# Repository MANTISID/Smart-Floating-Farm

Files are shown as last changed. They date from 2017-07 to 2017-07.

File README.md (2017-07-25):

# Smart-Floating-Farm
Future Farming Platform in Coastal and Remote Island. Cultivate the future, start from the sea. We submit this project to  Intel Hackathon 2017

## Inspiration
**We want to help people**

We see that local people in Coastal area and Remote Islands having difficulty in planting horticulture because they face the problem of land limitations. We have an idea about making floating platform so people can grow their vegetables at coastal area.
We inspired by [**GROASIS**](https://www.groasis.com/en), [**Seawater Greenhouse**](https://seawatergreenhouse.com/), and [**Hamster Ball-Shaped Solarball**](http://inhabitat.com/hamster-ball-shaped-solarball-uses-the-sun-to-purify-water/). They can grow plants at desert area and have a pure water using desalination process.
Hopefully this platform can help local people to reduce their dependence on supply from mainland, help them make their own food independence and also help to make more money from selling the harvest vegetables. We also can manage these process with supllying seed, provide consultation to user, and preparing the market to sell the vegetables.

## What it does
__**SMART FLOATING FARM (SFF) PLATFORM BUILD TO RECORD, MONITOR, AND MAKE DECISION BASED ON THE RECORD.**__

__**Initialize sensors and output**__

This platform will initialize serial, lcd, RTC (real time clock), sensors, and motor. If RTC cannot be detected, LCD will display error and user must fix it. After RTC is ok, Arduino101 will check communication with ESP8266. Arduino101 send "AT" and wait "OK" from ESP8266.
 
__**Get threshold from Server**__

After receiving "OK", Arduino will command ESP8266 as station mode and get parameter threshold from Server.  These threshold value used to ensure plants are in the range that has been determined by the user. SFF send GET method to server ([This link](http://mantisid.id/api/product/sff_th_r.php?Format=Sys) used to receive sensors threshold). Parameter threshold will be saved as variable.

__**Sensor Measurement**__

This platform record these parameters : soil moisture & temperature, greenhouse temperature & humidity, greenhouse smoke detection, vibration, plant height, time, and light intensity.
 
__**Sending Data to Server**__

Data from sensor compiled as String and send it to Web by ESP8266 using POST method ([Go to this link](http://mantisid.id/api/product/sff_dt_c.php) to send data to WebServer; [Visit this link](http://mantisid.id/api/product/sff_dt_r.php) to see data that received by WebServer from Platform).

__**Output Action**__

Arduino101 check data measurement with threshold received from Server. Based on these threshold, platform will give command automatically to activate LED indicator, water pump, exhaust fan and LED lamps based on sensors reading. After 10 seconds, platform will delay few minutes before the next measurement. While waiting, Arduino101 measure gyro value. 

## How we built it
We use Arduino IDE to built the firmware. We use libraries from internal Arduino IDE and from internet. For external library, we used  [SEEED RGB LCD ](https://github.com/Seeed-Studio/Grove_LCD_RGB_Backlight), [Adafruit DHT11 ](https://github.com/adafruit/DHT-sensor-library), [Adafruit RTC ](https://github.com/adafruit/RTClib), [Adafruit ADS1115 ](https://github.com/adafruit/Adafruit_ADS1X15), [MQ02 Gas Sensor](https://github.com/labay11/MQ-2-sensor-library), [Dallas DS18B20 ](https://github.com/milesburton/Arduino-Temperature-Control-Library), [Rotation from Gyro & Accelerometer](https://forum.arduino.cc/index.php?topic=378779.0), [Time Alarm ](https://github.com/michaelmargolis/arduino_time/tree/master/Time), and [Time Lib ](https://github.com/PaulStoffregen/Time). For internal library, we used Wire, pitches.h, CurieIMU and Software Serial. We used Mario Bros Tune developed by [Dipto Pratyaksa](http://www.linuxcircle.com/2013/03/31/playing-mario-bros-tune-with-arduino-and-piezo-buzzer/) to play sound at the beginning. IMU rotation angle we got from [Erikyo](https://forum.arduino.cc/index.php?topic=378779.0). SFF Arduino sketch can be found at [MANTIS GITHUB](https://github.com/MANTISID/Smart-Floating-Farm).

## Sensor and output configuration
**ARDUINO101   SENSOR/OUTPUT**
- D0    <---->    Tx UART
- D1    <---->    Rx UART
- D2    <---->    GREEN LED INDICATOR
- D3    <---->    RED LED INDICATOR
- D4    <---->    BUZZER
- D5    <---->    DHT11
- D6    <---->    SRF04 ECHO PIN
- D7    <---->    Tx ESP8266
- D8    <---->    Rx ESP8266
- D9    <---->    DS18B20
- D10   <---->    RELAY FOR EXHAUST FAN & SPRAYER
- D11   <---->    RELAY FOR WATER PUMP
- A0    <---->    VIBRATION SENSOR
- A1    <---->    LIGHT SENSOR
- A2    <---->    GREEN LED FOR LIGHTING
- A3    <---->    MQ02 GAS SENSOR

- A4    <---->    SDA
- A5    <---->    SCL

**I2C COMMUNICATION**
- RGB LCD SHIELD
- ADS1115 ADC 16 BIT
    * ADC1    <---->    SOIL MOISTURE SENSOR
    * ADC3    <---->    WATER LEVEL SENSOR
    
**INTERNAL USE:**
- INERTIAL MEASUREMENT UNIT (GYRO & ACCELEROMETER)

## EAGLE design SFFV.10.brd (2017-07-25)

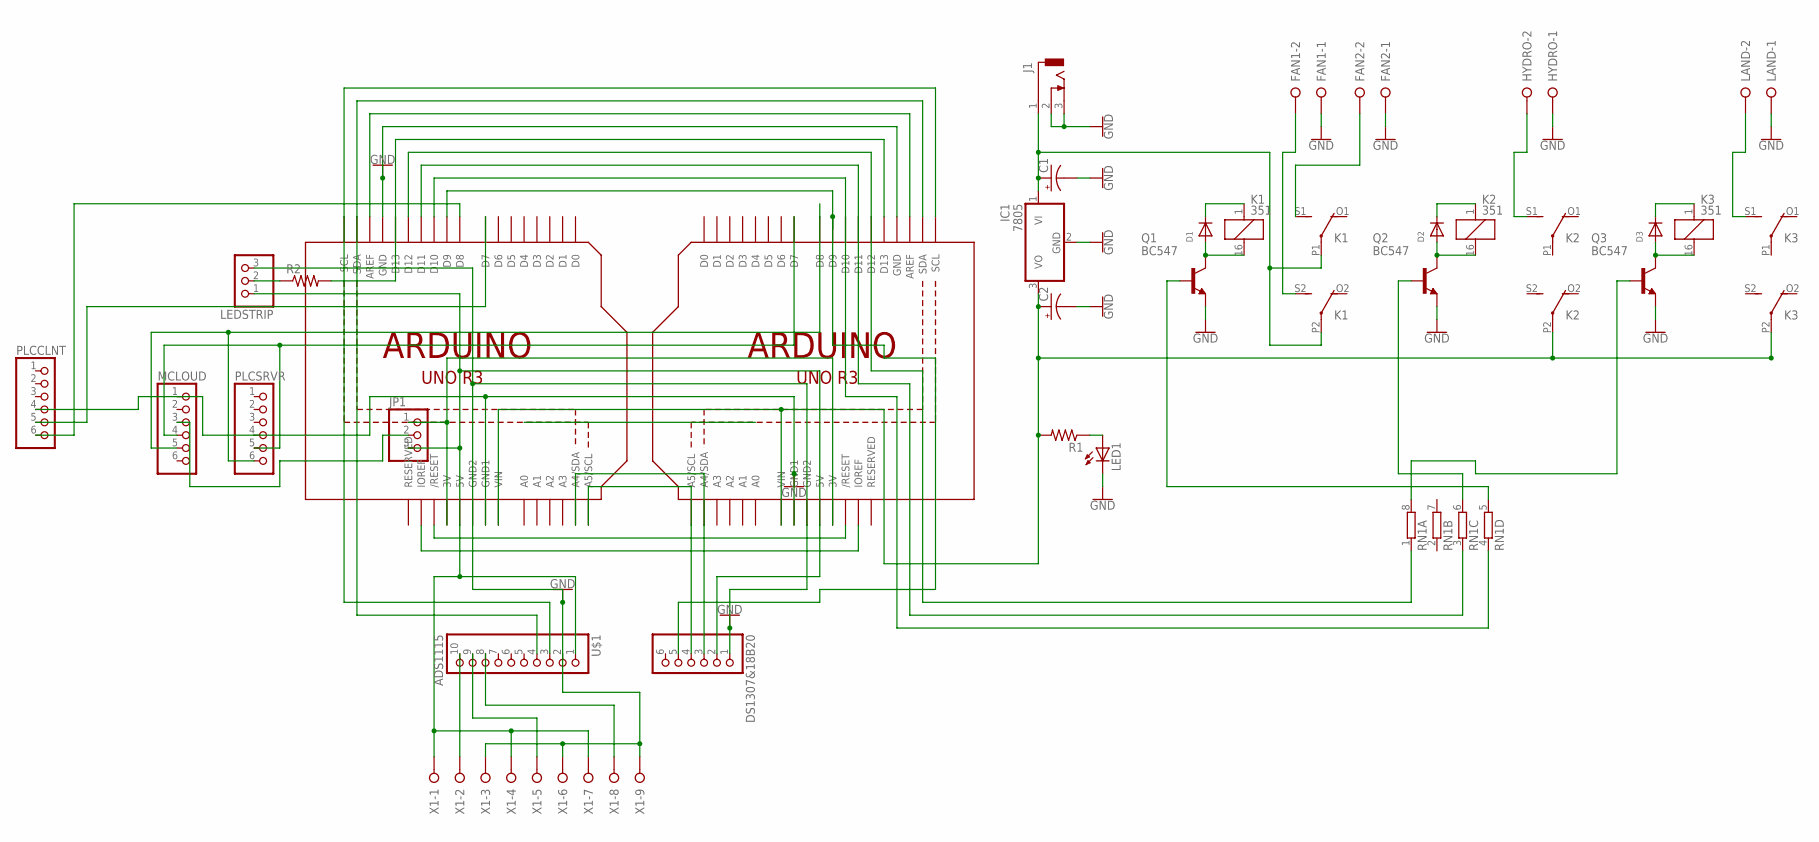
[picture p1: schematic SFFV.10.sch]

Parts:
C1, C2: CPOL-USE; PANASONIC_E
D1, D2, D3: DIODESMA; SMADIODE
DS1307&18B20: PINHD-1X6B; 1X06-BIG
FAN1, FAN2: W237-02P; W237-132
HYDRO: W237-02P; W237-132
IC1: 7805; TO220H
J1: DCJ0303
JP1: PINHD-1X3CB; 1X03-CLEANBIG
K1, K2, K3: 351
LAND: W237-02P; W237-132
LED1: LED5MM
LEDSTRIP: PINHD-1X3; 1X03
MCLOUD: PINHD-1X6B; 1X06-BIG
PLCCLNT: PINHD-1X6B; 1X06-BIG
PLCSRVR: PINHD-1X6B; 1X06-BIG
Q1, Q2, Q3: BC547; TO92
R1, R2: R-US_MELF0207W; MINI_MELF-0207W
RN1: 4R-NEXB38V; EXB38V
U1, U2: ARDUINOR3-BPLACE
U$1: ADS1115; 1X10-BIG
X1: W237-09P; W237-9P

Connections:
GND: C1.-, C2.-, DS1307&18B20.1, FAN1.1, FAN2.1, HYDRO.1, IC1.2 (GND), J1.2, J1.3, LAND.1, LED1.K (C), LEDSTRIP.3, MCLOUD.1, PLCCLNT.4, PLCSRVR.4, Q1.1 (E), Q2.1 (E), Q3.1 (E), U1.GND, U1.GND1, U1.GND2, U2.GND, U2.GND1, U2.GND2, U$1.2, X1.3, X1.6, X1.9
unnamed: LEDSTRIP.2, R2.1
unnamed: LED1.A, R1.1
unnamed: MCLOUD.4, PLCSRVR.5, U2.D7
unnamed: JP1.2, MCLOUD.3
unnamed: PLCCLNT.5, U1.D7
unnamed: DS1307&18B20.4, U1.A5 (A5/SCL), U2.A5 (A5/SCL)
unnamed: DS1307&18B20.3, U1.A4 (A4/SDA), U2.A4 (A4/SDA)
unnamed: MCLOUD.5, PLCSRVR.6, U2.D8
unnamed: JP1.1, U1.3V, U2.3V
unnamed: U1.RESET (/RESET), U2.RESET (/RESET)
unnamed: U1.IOREF, U2.IOREF
unnamed: PLCCLNT.6, U1.D8
unnamed: DS1307&18B20.5, U1.D9, U2.D9
unnamed: RN1.4 (1), U1.D10, U2.D10
unnamed: RN1.3 (1), U1.D11, U2.D11
unnamed: RN1.1, U1.D12, U2.D12
unnamed: R2.2, U1.D13, U2.D13
unnamed: U1.AREF, U2.AREF
unnamed: U1.SDA, U2.SDA, U$1.4
unnamed: U$1.10, X1.2
unnamed: C1.+, IC1.1 (VI), J1.1, K1.P1, K1.P2
unnamed: C2.+, IC1.3 (VO), K2.P2, K3.P2, R1.2, U1.VIN, U2.VIN
unnamed: Q1.2 (B), RN1.5 (2)
unnamed: Q2.2 (B), RN1.6 (2)
unnamed: HYDRO.2, K2.S1 (S)
unnamed: Q3.2 (B), RN1.8 (2)
unnamed: D1.A, K1.16 (2), Q1.3 (C)
unnamed: D1.C, K1.1
unnamed: D2.A, K2.16 (2), Q2.3 (C)
unnamed: D2.C, K2.1
unnamed: D3.A, K3.16 (2), Q3.3 (C)
unnamed: D3.C, K3.1
unnamed: FAN2.2, K1.S1 (S)
unnamed: FAN1.2, K1.S2 (S)
unnamed: K3.S1 (S), LAND.2
unnamed: U$1.9, X1.5
unnamed: U$1.8, X1.8
unnamed: U1.SCL, U2.SCL, U$1.3
PLCCLNT: DS1307&18B20.2, JP1.3, LEDSTRIP.1, U1.5V, U2.5V, U$1.1, X1.1, X1.4, X1.7

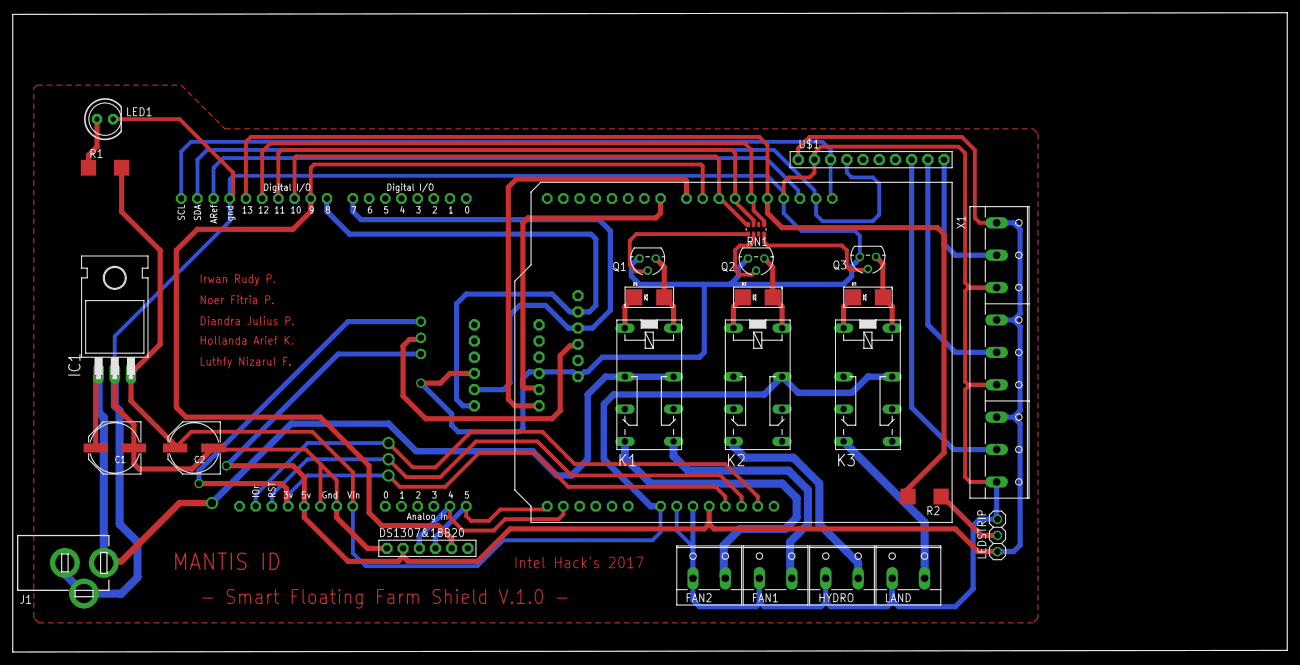
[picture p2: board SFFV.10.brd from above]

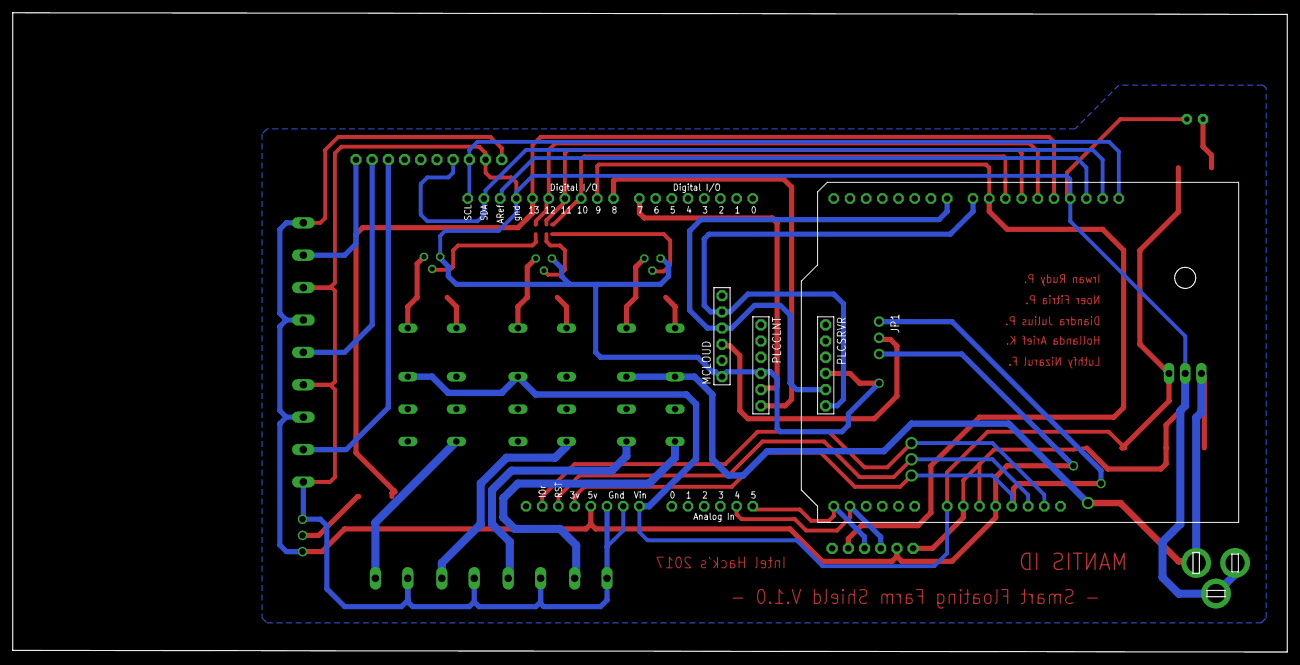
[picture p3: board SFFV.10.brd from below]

Board: 2 copper layers, 199.9 x 100.3 mm, 31 parts (5 on the bottom side), 40 nets.

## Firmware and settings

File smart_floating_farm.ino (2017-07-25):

#include <Wire.h>               // Library for I2C communication
#include "rgb_lcd.h"            // RGB LCD SEEED
#include "DHT.h"                // Adafruit dht library
#include "RTClib.h"             // Adafruit RTC library
#include "pitches.h"            // Tone note code
#include <MQ2.h>                // MQ2 gas sensor library.
#include <DallasTemperature.h>  // DS18B20 library. By : Miles Burton, Tim Newsome, and Guil Barros
#include <Adafruit_ADS1015.h>   // Adafruit ADS1115 16 bit ADC library.
#include <TimeLib.h>            // Time library
#include <TimeAlarms.h>         // Library for Set alarm. By : Michael Margolis 2008-2011
#include <CurieIMU.h>           // Library for GYRO
#include <SoftwareSerial.h>     // Serial library for communicate with ESP8266

//SOFTWARE SERIAL
#define rxPin 7
#define txPin 8
SoftwareSerial serial(rxPin, txPin);

// IMU - we use codes from erikyo. Source : https://forum.arduino.cc/index.php?topic=378779.0
float FS_SEL = 131;                                  // IMU gyro values to degrees/sec
unsigned long last_read_time;
float last_x_angle, last_y_angle, last_z_angle;      // These are the filtered angles
float lGXA, lGYA, lGZA;                              // Store the gyro angles to compare drift
// FUNCTIONS
//Math
//Convert radians to degrees
double rtod(double fradians) {
  return (fradians * 180.0 / PI);
}

//Mario main theme melody by: Dipto Pratyaksa
#define melodyPin 4
int melody[] = {
  NOTE_E7, NOTE_E7, 0, NOTE_E7,
  0, NOTE_C7, NOTE_E7, 0,
  NOTE_G7, 0, 0,  0,
  NOTE_G6, 0, 0, 0,

  NOTE_C7, 0, 0, NOTE_G6,
  0, 0, NOTE_E6, 0,
  0, NOTE_A6, 0, NOTE_B6,
  0, NOTE_AS6, NOTE_A6, 0,

  NOTE_G6, NOTE_E7, NOTE_G7,
  NOTE_A7, 0, NOTE_F7, NOTE_G7,
  0, NOTE_E7, 0, NOTE_C7,
  NOTE_D7, NOTE_B6, 0, 0,

  NOTE_C7, 0, 0, NOTE_G6,
  0, 0, NOTE_E6, 0,
  0, NOTE_A6, 0, NOTE_B6,
  0, NOTE_AS6, NOTE_A6, 0,

  NOTE_G6, NOTE_E7, NOTE_G7,
  NOTE_A7, 0, NOTE_F7, NOTE_G7,
  0, NOTE_E7, 0, NOTE_C7,
  NOTE_D7, NOTE_B6, 0, 0
};

//Mario main them tempo by: Dipto Pratyaksa
int tempo[] = {
  12, 12, 12, 12,
  12, 12, 12, 12,
  12, 12, 12, 12,
  12, 12, 12, 12,

  12, 12, 12, 12,
  12, 12, 12, 12,
  12, 12, 12, 12,
  12, 12, 12, 12,

  9, 9, 9,
  12, 12, 12, 12,
  12, 12, 12, 12,
  12, 12, 12, 12,

  12, 12, 12, 12,
  12, 12, 12, 12,
  12, 12, 12, 12,
  12, 12, 12, 12,

  9, 9, 9,
  12, 12, 12, 12,
  12, 12, 12, 12,
  12, 12, 12, 12,
};

/*DEFINE PARAMETER FOR SENSOR AND COMPONENTS*/
Adafruit_ADS1115 ads;   // ADS1115
AlarmId id;            // ALARM FOR SHOWERING THE PLANT
MQ2 mq2(A3);            // MQ02 GAS SENSOR
RTC_DS1307 rtc;         // RTC DS1307
const int pingPin = 6;  // ECHO PIN SRF04
#define motor_air   10
#define motor_soil  11

//D18B20
#define ONE_WIRE_BUS 9
OneWire oneWire(ONE_WIRE_BUS);
DallasTemperature sensors(&oneWire);
DeviceAddress insideThermometer;

//RGB LCD DEFINITION
rgb_lcd lcd;
const int colorR = 255;
const int colorG = 255;
const int colorB = 0;

//DHT11
#define DHTPIN 5
#define DHTTYPE DHT11
DHT dht(DHTPIN, DHTTYPE);

//GLOBAL VARIABEL
char c, ch;
char reply[500];
byte n = 0;
byte hours, hours1, minutes, minutes1, waktu;
int i, j, smoke, smoke_max, waktu1, panjang;

int mois_min, mois_max, SoilTemp_max, WaterLevel_min, WaterLevel_max, AirTemp_max;
int humid_min, humid_max, light_min;
int16_t adc0, adc1, adc2, adc3;
double ads_max = 32767.0;
long duration, cm;
unsigned long microsNow;

float roll, pitch, heading;
float water, soil, light, temp, humid, vibration, water_temp;
String dates, clocks, data;
String result, teks, hasil, PostData, postrequest;
boolean No_IP = false;
String IP = "";

void setup() {
  //SETTING LCD
  lcd.begin(16, 2);
  lcd.setRGB(colorR, colorG, colorB);
  lcd.clear();

  //SETTING SERIAL
  pinMode(rxPin, INPUT);
  pinMode(txPin, OUTPUT);
  Serial.begin(9600);
  serial.begin(9600);

  //SETTING LED, BUZZER, & MOTOR
  pinMode(2, OUTPUT);        // GREEN LED
  pinMode(3, OUTPUT);        // RED LED
  pinMode(4, OUTPUT);        // BUZZER
  pinMode(A2, OUTPUT);       // GREEN LED
  digitalWrite(A2, HIGH);
  delay(1000);
  pinMode(motor_air, INPUT);  // FAN
  pinMode(motor_soil, INPUT); // MOTOR FOR SHOWERING SOIL & WATER

  //SETTING SENSORS
  dht.begin();  // DHT11
  ads.begin();  // ADS1115
  mq2.begin();  // MQ02

  delay(5000);
  lcd.setCursor(1, 0);
  lcd.print(F("SMART FLOATING"));
  lcd.setCursor(5, 1);
  lcd.print(F("FARM"));
  delay(10000);
  lcd.clear();
  lcd.setCursor(0, 0);
  lcd.print(F("----  SFF  -----"));
  lcd.setCursor(0, 1);
  lcd.print("-- MANTIS ID ---");

  //CHECK RED AND GREEN LED
  digitalWrite(2, HIGH);
  delay(3000);
  digitalWrite(2, LOW);
  digitalWrite(3, HIGH);
  delay(3000);
  digitalWrite(3, LOW);

  //SERIAL MONITOR CHECK
  Serial.println("Smart Floating Farm - MANTIS ID");

  //GYRO+ACCELEROMETER -------------------
  lcd.clear();
  lcd.print("Calibrate GYRO");
  CurieIMU.begin();
  // use the code below to calibrate accel/gyro offset values
  Serial.println("Internal sensor offsets BEFORE calibration...");
  Serial.print(CurieIMU.getXAccelOffset());
  Serial.print("\t");
  Serial.print(CurieIMU.getYAccelOffset());
  Serial.print("\t");
  Serial.print(CurieIMU.getZAccelOffset());
  Serial.print("\t");
  Serial.print(CurieIMU.getXGyroOffset());
  Serial.print("\t");
  Serial.print(CurieIMU.getYGyroOffset());
  Serial.print("\t");
  Serial.println(CurieIMU.getZGyroOffset());
  Serial.println("About to calibrate. Make sure your board is stable and upright");
  delay(1000);
  // The board must be resting in a horizontal position for the following calibration procedure to work correctly!
  Serial.print("Starting Gyroscope calibration...");
  CurieIMU.autoCalibrateGyroOffset();
  Serial.println(" Done");
  Serial.print("Starting Acceleration calibration...");
  CurieIMU.autoCalibrateXAccelOffset(0);
  CurieIMU.autoCalibrateYAccelOffset(0);
  CurieIMU.autoCalibrateZAccelOffset(1);
  Serial.println(" Done");
  Serial.println("Enabling Gyroscope/Acceleration offset compensation");
  CurieIMU.setGyroOffsetEnabled(true);
  CurieIMU.setAccelOffsetEnabled(true);

  set_last_read_angle_data(millis(), 0, 0, 0, 0, 0, 0);
  delay(1000);

  //BUZZER PLAY MARIO BROS RINGTONE
  lcd.clear();
  lcd.print("Mario Bros Tone");
  sing();
  delay(1000);

  lcd.clear();
  lcd.print("Check RTC Module");
  //CHECK RTC MODULE
  Serial.println(F("Check RTC module"));
  if (! rtc.begin()) {
    digitalWrite(2, HIGH);
    digitalWrite(3, LOW);
    Serial.println("Couldn't find RTC");
    lcd.clear();
    lcd.setCursor(5, 0);
    lcd.print(F("ERROR!")); //Please run the SetTime
    lcd.setCursor(0, 1);
    lcd.print(F("   CONTACT CS"));
    while (1);
  }
  if (! rtc.isrunning()) {
    digitalWrite(2, HIGH);
    digitalWrite(3, LOW);
    Serial.println("Couldn't find RTC");
    lcd.clear();
    lcd.setCursor(5, 0);
    lcd.print(F("ERROR!")); //Please run the SetTime
    lcd.setCursor(0, 1);
    lcd.print(F("   CONTACT CS"));
    while (1);
  }

  delay(1000);
  lcd.clear();
  lcd.print("Everything is OK");
  lcd.setCursor(0, 1);
  lcd.print("Warming ESP8266");
  delay(5000);

  // CHECK IF ESP8266 IS CONNECTED AND CAN RECEIVE AT COMMAND
  lcd.clear();
  lcd.print("Finding ESP8266");
  Serial.println("Finding ESP8266");//check via serial monitor
  delay(5000);

  //CHECK IF ESP8266 CAN COMMUNICATE. IF STILL ERROR HIT ESP8266 RESET BUTTON
  while (1) {
    ConnectAT("AT", 100);
    if (result == "OK") {
      break;
    }
  }
  lcd.clear();

  Serial.println(F("Set as station"));
  lcd.print(F("SET AS STATION")); //SET ESP8266 AS STATION MODE
  Connect("AT+CWMODE=1", 100);
  delay(1000);
  lcd.clear();

  Serial.println(F("Disconnecting AP"));
  lcd.print(F("DISCONNECT AP...")); //DISCONNECT FROM AP
  Connect("AT+CWQAP", 100);
  delay(1000);
  lcd.clear();

  lcd.print(F("SET DHCP...")); //SET DHCP
  Connect("AT+CWDHCP=1,1", 100);
  delay(1000);
  lcd.clear();

  Serial.println(F("Connecting WIFI"));
  lcd.print("Connecting Wifi"); //CONNECT TO AP
  //connect_wifi("AT+CWJAP=\"My ASUS holland\",\"dunedin1996\"", 5000);   //provide your WiFi username and password here
  connect_wifi("AT+CWJAP=\"Lenovo X2-AP\",\"16756205\"", 5000);
  delay(1000);
  lcd.clear();

  lcd.print(F("Get IP")); //GET ESP IP ADDRESS
  get_ip();
  Serial.println(IP);
  delay(2000);
  lcd.clear();

  //GREEN LED ACTIVE INDICATE EVERTHING IS OK
  digitalWrite(3, HIGH);
  digitalWrite(2, LOW);
}

void loop() {
  unsigned long startTime = 0;
  startTime = millis();
  pinMode(motor_air, INPUT);
  pinMode(motor_soil, INPUT);

  //SET ESP FOR TCP COMMUNICATION
  lcd.print(F("CIPMODE")); //CIPMODE
  Connect("AT+CIPMODE=0", 100);
  delay(1000);
  lcd.clear();
  lcd.print("SingleConnection");
  setnet("AT+CIPMUX=0", 100);
  delay(1000);
  lcd.clear();

  //CONNECT TO SERVER
  lcd.print("CONNECT SERVER");
  InetStart("AT+CIPSTART=\"TCP\",\"www.mantisid.id\",80", 100);
  delay(1000);
  lcd.clear();

  if (result == "error") {
    // ERROR GET SO USE INTERNAL VALUE THRESHOLD
    parameter();
    Serial.println(F("Get default parameter"));
  }
  else {
    // GET PARAMETER FROM SERVER;
    Serial.println(F("Get parameter from server"));
    lcd.print("GET PARAMETER...");
    teks = "GET /api/product/sff_th_r.php?Format=Sys HTTP/1.1\r\nHost: www.mantisid.id\r\n\r\n\r\n";//Connection: close
    panjang = teks.length();
    serial.print("AT+CIPSEND=");
    serial.println(panjang);
    Serial.print("AT+CIPSEND=");
    Serial.println(panjang);
    delay(500);
    serial.print(teks);
    cipsend(5000);
    delay(500);
    lcd.clear();
    lcd.print(F("Close Connection")); //SET ESP8266 AS STATION MODE
    Serial.println("AT+CIPCLOSE");
    serial.println("AT+CIPCLOSE");
    lcd.clear();
    lcd.print("Got Server");
    lcd.setCursor(0, 1);
    lcd.print("Parameter");
    parsingdata();
  }

  //SET TIME FOR SHOWERING THE PLANT
  Alarm.timerRepeat(hours, minutes, 0, siram);    // timer for every 1 seconds
  Alarm.timerRepeat(hours1, minutes1, 0, siram);
  Alarm.delay(0);

  //READ SENSORS
  //USIRR ********************
  pinMode(pingPin, OUTPUT);
  digitalWrite(pingPin, LOW);
  delayMicroseconds(2);
  digitalWrite(pingPin, HIGH);
  delayMicroseconds(5);
  digitalWrite(pingPin, LOW);
  //ping sensor measurement
  pinMode(pingPin, INPUT);
  duration = pulseIn(pingPin, HIGH);
  // convert the time into a distance
  cm = microsecondsToCentimeters(duration);
  cm = 17 - cm;
  //*********************************

  //DHT11
  humid = dht.readHumidity();
  temp = dht.readTemperature();
  //ANALOG SENSORS
  vibration = analogRead(A0) / 1023.0 * 100.0;
  light = analogRead(A1) / 1023.0 * 100.0;
  smoke = mq2.readSmoke();

  //ADS1115 measurement
  adc0 = ads.readADC_SingleEnded(3);
  adc1 = ads.readADC_SingleEnded(1);
  if (adc0 > 20000) //water level maximum value when all part in water
    adc0 = 20000;
  water = adc0 / 20000.00 * 100.0;
  soil = adc1 / ads_max * 100.0;

  //DS18B20
  sensors.requestTemperatures();
  water_temp = sensors.getTempCByIndex(0);

  //GYRO+ACCELEROMETER ----------------------------------------------------
  unsigned long t_now = millis();
  int ax = CurieIMU.getAccelerationX();
  int ay = CurieIMU.getAccelerationY();
  int az = CurieIMU.getAccelerationZ();
  int gx = CurieIMU.getRotationX();
  int gy = CurieIMU.getRotationY();
  int gz = CurieIMU.getRotationZ();

  // Convert gyro values to degrees/sec
  float gyro_x = gx / FS_SEL;
  float gyro_y = gy / FS_SEL;
  float gyro_z = gz / FS_SEL;

  // Compute the accel angles
  float accelX = rtod(atan(ay / sqrt( pow(ax, 2) + pow(az, 2))));
  float accelY = rtod(-1 * atan(ax / sqrt(pow(ay, 2) + pow(az, 2))));

  // Compute the (filtered) gyro angles
  float dt = (t_now - last_read_time) / 1000.0;
  float gyroX = gyro_x * dt + last_x_angle;
  float gyroY = gyro_y * dt + last_y_angle;
  float gyroZ = gyro_z * dt + last_z_angle;

  // Compute the drifting gyro angles
  float unfiltered_gyro_angle_x = gyro_x * dt + lGXA;
  float unfiltered_gyro_angle_y = gyro_y * dt + lGYA;
  float unfiltered_gyro_angle_z = gyro_z * dt + lGZA;

  // Apply the complementary filter to figure out the change in angle
  // Alpha depends on the sampling rate...
  float alpha = 0.96;
  pitch = alpha * gyroX + (1.0 - alpha) * accelX;
  roll = alpha * gyroY + (1.0 - alpha) * accelY;
  heading = gyroZ;  //Accelerometer doesn't give z-angle

  // Update the saved data with the latest values
  set_last_read_angle_data(t_now, pitch, roll, heading, unfiltered_gyro_angle_x, unfiltered_gyro_angle_y, unfiltered_gyro_angle_z);
  //************************************************************************************************

  //DISPLAY+SEND DATA
  DateTime now = rtc.now();
  dates = String(now.year(), DEC) + '-' + print2digit(now.month()) + '-' + print2digit(now.day());
  clocks = print2digit(now.hour()) + ':' + print2digit(now.minute()) + ':' + print2digit(now.second());

  //COMPILE DATA
  data = "{\"Data\": \"\'" + dates + " " + clocks + "\'";
  data = data + ",'" + String (soil) + "','" + String (water_temp)  + "','" + String (cm) + "','" ;
  data = data + String (water) + "','" + String (temp) + "','" + String (humid) + "','" + String (light);
  data = data + "','" + String (smoke) + "','" + String (vibration) + "','" + String (pitch) + "','" + String (roll) + "','" + String(heading) + "','" + "MANTIS" + "'\"}";

  //SEND TO SERVER
  postrequest = "POST /api/product/sff_dt_c.php HTTP/1.1\r\nHost: www.mantisid.id\r\nAccept: */*\r\nContent-Length: ";
  postrequest = postrequest + data.length() + "\r\n" + "Content-Type: application/x-www-form-urlencoded\r\n" + "\r\n" + data;

  lcd.clear();
  lcd.print("CONNECT SERVER");
  InetStart("AT+CIPSTART=\"TCP\",\"www.mantisid.id\",80", 100);
  delay(1000);
  lcd.clear();
  lcd.print("Send Data:");
  lcd.print(data.length());
  serial.print("AT+CIPSEND=");
  serial.println(postrequest.length());
  delay(100);
  serial.println(postrequest);

  lcd.setCursor(0, 1);
  lcd.print("Sending");

  delay(500);
  lcd.setCursor(0, 1);
  lcd.print("              ");
  lcd.setCursor(0, 1);
  lcd.print("Packet Sent");
  while (serial.available()) {
    String tmpResp = serial.readString();
    Serial.println(tmpResp);
  }

  serial.println("AT+CIPCLOSE");
  lcd.clear();
  lcd.print("AT+CIPCLOSE");
  //SEND TO SERIAL TO CHECK DATA OUTPUT
  Serial.print(data);
  Serial.print("|Time ");
  delay(1000);

  //DISPLAY ON LCD
  lcdprint();
  //SET OUTPUT BASED ON THRESHOLD
  output();
  delay(1000);
  lcd.clear();
  lcd.print(F("- SFF MANTISID -"));
  lcd.setCursor(0, 1);
  lcd.print(F("Wait 4 Next Data"));
  i = 0;
  waktu1 = millis() - startTime;
  Serial.print(waktu1);
  waktu1 = waktu * 60 * 1000 - waktu1; waktu1 = 60000;
  Serial.print(" ");
  Serial.println(waktu1);

  //delay for next data, while delay keep record gyro to maintan the data
  while (i < waktu1) {
    //GYRO+ACCELEROMETER ----------------------------------------------------
    unsigned long t_now = millis();
    int ax = CurieIMU.getAccelerationX();
    int ay = CurieIMU.getAccelerationY();
    int az = CurieIMU.getAccelerationZ();
    int gx = CurieIMU.getRotationX();
    int gy = CurieIMU.getRotationY();
    int gz = CurieIMU.getRotationZ();

    // Convert gyro values to degrees/sec
    float gyro_x = gx / FS_SEL;
    float gyro_y = gy / FS_SEL;
    float gyro_z = gz / FS_SEL;

    // Compute the accel angles
    float accelX = rtod(atan(ay / sqrt( pow(ax, 2) + pow(az, 2))));
    float accelY = rtod(-1 * atan(ax / sqrt(pow(ay, 2) + pow(az, 2))));

    // Compute the (filtered) gyro angles
    float dt = (t_now - last_read_time) / 1000.0;
    float gyroX = gyro_x * dt + last_x_angle;
    float gyroY = gyro_y * dt + last_y_angle;
    float gyroZ = gyro_z * dt + last_z_angle;

    // Compute the drifting gyro angles
    float unfiltered_gyro_angle_x = gyro_x * dt + lGXA;
    float unfiltered_gyro_angle_y = gyro_y * dt + lGYA;
    float unfiltered_gyro_angle_z = gyro_z * dt + lGZA;

    // Apply the complementary filter to figure out the change in angle
    // Alpha depends on the sampling rate...
    float alpha = 0.96;
    pitch = alpha * gyroX + (1.0 - alpha) * accelX;
    roll = alpha * gyroY + (1.0 - alpha) * accelY;
    heading = gyroZ;  //Accelerometer doesn't give z-angle

    // Update the saved data with the latest values
    set_last_read_angle_data(t_now, pitch, roll, heading, unfiltered_gyro_angle_x, unfiltered_gyro_angle_y, unfiltered_gyro_angle_z);

    delay(1);
    i++;
  }
}

void set_last_read_angle_data(unsigned long time, float x, float y, float z, float x_gyro, float y_gyro, float z_gyro) {
  last_read_time = time;
  last_x_angle = x; last_y_angle = y; last_z_angle = z;
  lGXA = x_gyro; lGYA = y_gyro; lGZA = z_gyro;
}

long microsecondsToCentimeters(long microseconds) {
  // The speed of sound is 340 m/s or 29 microseconds per centimeter.
  // The ping travels out and back, so to find the distance of the
  // object we take half of the distance travelled.
  return microseconds / 29 / 2;
}

String print2digit(byte num) {
  String data;
  if (num >= 0 && num < 10)
  {
    data = '0' + String(num);
  }
  else
  {
    data = String(num);
  }
  return data;
}

void siram() { //showering plant for 1 minute
  for (byte i = 0; 1 < 6; i++) {
    pinMode(motor_soil, OUTPUT);
    digitalWrite(motor_soil, HIGH);
    delay(3 * 1000);
    pinMode(10, INPUT);
    pinMode(11, INPUT);
    delay(2 * 1000);
  }
}

void parameter() {
  hours = 7;      //hour for showering plant in the morning
  hours1 = 16;      //hour for showering plant in the evening
  minutes = 0;      //minute for showering plant in the morning
  minutes1 = 0;     //minute for showering plant in the evening
  waktu = 5;      //delay for next data
  mois_min = 30;    //minimum threshold for soil moisture
  mois_max = 75;    //maximum threshold for soil moisture
  SoilTemp_max = 35;  //maximum threshold for soil temperature
  WaterLevel_min = 20;  //minimum threshold for water level
  WaterLevel_max = 75;  //maximum threshold for water level
  AirTemp_max = 33;   //maximum threshold for air temperature
  humid_min = 40;   //minimum threshold for humid
  humid_max = 75;   //maximum threshold for humid
  light_min = 15;   //minimum threshold for light intensity
  smoke_max = 2000;   //maximum threshold for smoke
  lcd.print("Default");
  lcd.setCursor(0, 1);
  lcd.print("Parameter");
}

void sing() { //play mario bros tune
  // iterate over the notes of the melody:
  int size = sizeof(melody) / sizeof(int);
  for (int thisNote = 0; thisNote < size; thisNote++) {

    // to calculate the note duration, take one second
    // divided by the note type.
    //e.g. quarter note = 1000 / 4, eighth note = 1000/8, etc.
    int noteDuration = 1000 / tempo[thisNote];

    buzz(melodyPin, melody[thisNote], noteDuration);

    // to distinguish the notes, set a minimum time between them.
    // the note's duration + 30% seems to work well:
    int pauseBetweenNotes = noteDuration * 1.30;
    delay(pauseBetweenNotes);

    // stop the tone playing:
    buzz(melodyPin, 0, noteDuration);
  }
}

void buzz(int targetPin, long frequency, long length) {
  long delayValue = 1000000 / frequency / 2; // calculate the delay value between transitions
  //// 1 second's worth of microseconds, divided by the frequency, then split in half since
  //// there are two phases to each cycle
  long numCycles = frequency * length / 1000; // calculate the number of cycles for proper timing
  //// multiply frequency, which is really cycles per second, by the number of seconds to
  //// get the total number of cycles to produce
  for (long i = 0; i < numCycles; i++) { // for the calculated length of time...
    digitalWrite(targetPin, HIGH); // write the buzzer pin high to push out the diaphram
    delayMicroseconds(delayValue); // wait for the calculated delay value
    digitalWrite(targetPin, LOW); // write the buzzer pin low to pull back the diaphram
    delayMicroseconds(delayValue); // wait again or the calculated delay value
  }
}

void lcdprint() {
  lcd.clear();
  lcd.setCursor(0, 0);
  lcd.print(dates);
  lcd.setCursor(0, 1);
  lcd.print(clocks);
  delay(2000);
  lcd.clear();
  lcd.setCursor(0, 0);
  lcd.print(F("soil="));
  lcd.print(soil);
  lcd.setCursor(0, 1);
  lcd.print(F("water temp="));
  lcd.print(water_temp, 2);
  delay(2000);
  lcd.clear();
  lcd.setCursor(0, 0);
  lcd.print(F("height="));
  lcd.print(cm);
  lcd.setCursor(0, 1);
  lcd.print(F("water lvl="));
  lcd.print(water, 2);
  delay(2000);
  lcd.clear();
  lcd.setCursor(0, 0);
  lcd.print(F("temp="));
  lcd.print(temp, 2);
  lcd.setCursor(0, 1);
  lcd.print(F("humid="));
  lcd.print(humid, 2);
  delay(2000);
  lcd.clear();
  lcd.setCursor(0, 0);
  lcd.print(F("light="));
  lcd.print(light, 2);
  lcd.setCursor(0, 1);
  lcd.print(F("smoke="));
  lcd.print(smoke);
  delay(2000);
  lcd.clear();
  lcd.setCursor(0, 0);
  lcd.print(F("vibrate="));
  lcd.print(vibration, 2);
  lcd.setCursor(0, 1);
  lcd.print(F("pitch="));
  lcd.print(pitch, 2);
  delay(2000);
  lcd.clear();
  lcd.setCursor(0, 0);
  lcd.print(F("roll="));
  lcd.print(roll, 2);
  lcd.setCursor(0, 1);
  lcd.print(F("heading="));
  lcd.print(heading, 2);
}
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

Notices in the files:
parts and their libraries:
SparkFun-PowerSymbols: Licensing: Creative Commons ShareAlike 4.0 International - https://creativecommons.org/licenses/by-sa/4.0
